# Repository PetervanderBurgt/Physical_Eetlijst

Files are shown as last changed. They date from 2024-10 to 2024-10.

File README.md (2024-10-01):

# Physical Eetlijst
Physical Eetlijst is a personal project to interface with the popular dutch student houses website [Eetlijst](https://eetlijst.nl/) and create a physical representation of the statuses of the website which shows who is there for dinner.

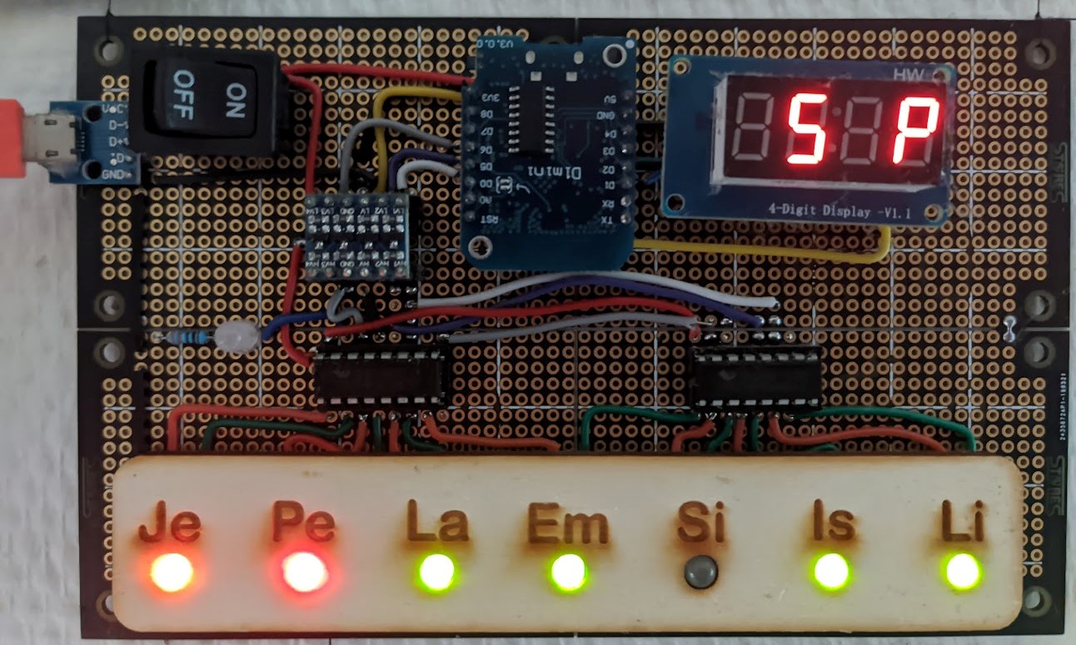
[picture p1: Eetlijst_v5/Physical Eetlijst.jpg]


## Inspiration
This Physical Eetlijst was first inspired by others living on the University of Twente campus, all credits for the idea should be given to them.
The model presented here is a simplified version just to show the statuses and how many people are eating, it is not possible to sign up for dinner through this physical device.

## Hardware
The hardware (and prototype board layout) can be seen in the Eetlijst v5 folder, it is given both as a [Fritzing](Eetlijst_v5/Eetlijst.fzz) and [png](Eetlijst_v5/Eetlijst_Hardware%20Breadboard%20layout.png) and [jpg](Eetlijst_v5/Eetlijst_Hardware%20Breadboard%20layout.jpg).
Pay close attention to the connections as it otherwise may not work.
For the Wemos D1 mini, the MCU is flipped in the image (meaning 5V should be in the upper right corner, and 3.3V should be in the Upper Left.
The necessary items are the following:

**Item**   | **Count** | **Description**
------------- | ------------- | -------------
**Necessities** ||
Prototype board | 1 | This should be approximately (32 by 50) for 7 people, this should be altered to fit.
Power connector breakout board | 1 | In the overview a USB micro is chosen, as that was what was available.
Power switch | 1 | Can be chosen as one sees fit.
Wemos D1 mini (clone) | 1 |Tthe brain of the operation is a ESP8266, in this case a clone Wemos D1 mini.
TM1637 | 1 | A simple display to show how many people will be eating.
Wires |N.A.| Some spare wires to connect everything.
Headers |N.A.| Some spare headers to make everything swappable.
**Indicators** ||
Blue LED | 1 | Indicator for when information is getting retrieved.
RG LED | x | A bicolour led, in my case Red and Green to show the status of the people. Get as many as there are people in Eetlijst, in this example 7.
Shift Register (74HC595) | x/4 | Shift register for driving LEDs, get the amount of bicolour LEDs divided by 4.
Level Shifter | 1 | To convert signals from 3.3V ESP8266 to 5V shift registers.
**OR** | | Instead of the above for indicators, there may be an easier option, this does require modifications for the hardware of the system.
Digital LED Strip (ws281x) | x + 1 | A digital LED strip may be easier than the above to indicate the people and when the system is retrieving information.

## Software
The Arduino IDE can be used to flash the software found in [Eetlijst_final_v5](Eetlijst_v5/Eetlijst_final_v5) to the Wemos D1 mini.
Before flashing, the different login credentials should be filled in [keys.h](Eetlijst_v5/Eetlijst_final_v5/keys.h).
In the place of the xxxxxxxx the Wi-Fi credentials, as well as the Eetlijst credentials should be filled in.

## Limitations
The current limitation of the system is that the ESP8266 does not work with enterprise networks, and will only work with simple home networks.
Furthermore, it is not possible to change your status from the device, this should still be done through the website or phone apps.

## Versions
There are two versions, the older one [Eetlijst_v4](Eetlijst_v4), is non-working, due to the updates given to Eetlijst itself.
The current version, [Eetlijst_v5](Eetlijst_v5), should be working and running.

## Support
This repository is for documentation purposes only, there will be no support for any issues. Questions are welcome, but it is not guaranteed to be fixed.

### License
[MIT](https://choosealicense.com/licenses/mit/)

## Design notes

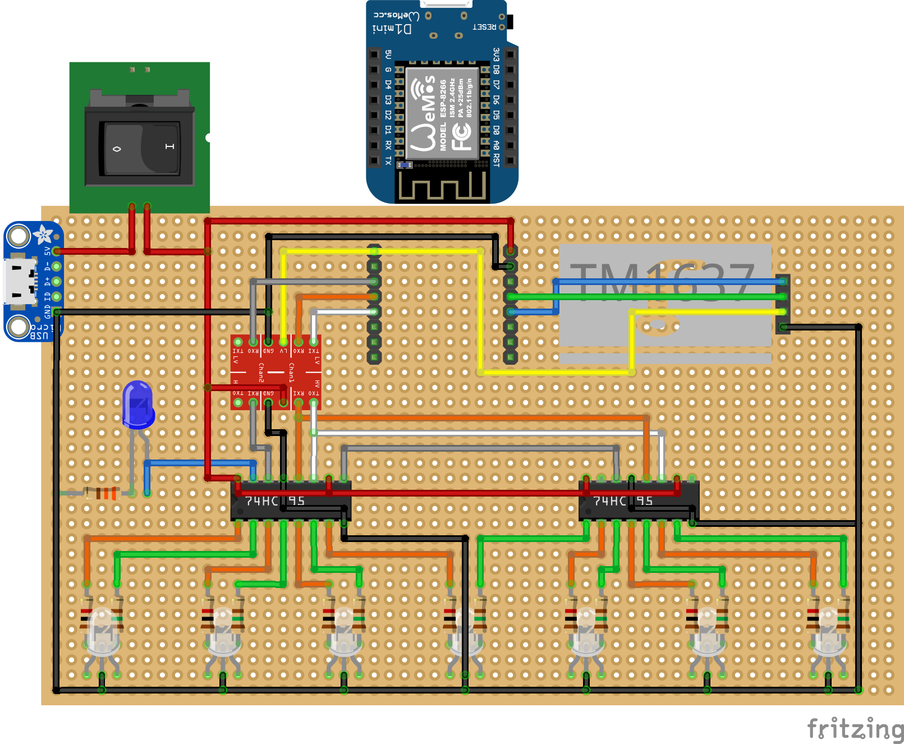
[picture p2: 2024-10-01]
Eetlijst_v5/Eetlijst_Hardware Breadboard layout.png

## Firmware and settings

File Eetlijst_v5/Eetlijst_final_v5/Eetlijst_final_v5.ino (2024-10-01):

//for general wifi and website connectivity
#include <ESP8266WiFi.h>
#include <ESP8266HTTPClient.h>
#include <WiFiClientSecure.h>
//for getting jsons
#include <ArduinoJson.h>
//for time
#include <WiFiUdp.h>
#include <NTPClient.h>


//Display
#include <TM1637Display.h>
#include "keys.h"

// WiFi parameters and eetlijst parameter to be configured to be configured
const char* ssid = DEFINED_SSID; // Hoofdlettergevoelig
const char* password = DEFINED_SSID_PASSWORD; // Hoofdlettergevoelig
const String Eetlijst_USERNAME = DEFINED_EETLIJST_USERNAME;
const String Eetlijst_PASSWORD = DEFINED_EETLIJST_PASSWORD;

//eetlijst parametes, in this example 7 people
const int noOfPeople = 7;
int red[noOfPeople];
int green[noOfPeople];
int blue = LOW;

//Display
// Module connection pins (Digital Pins)
#define CLK D2
#define DIO D3
TM1637Display display(CLK, DIO);

//ShiftRegister
#define latchPin D6
#define clockPin D5
#define dataPin D7

//variables for the token retrieval url and the api url
const char *token_url = "node.samenn.nl";
const char *api_url = "api.samenn.nl";
String retrieved_token = "";
//String which contains the number of people for query
const String Eetlijst_NUMBEROFPEOPLE = String(noOfPeople);

//should be in format yyyy-mm-dd (2023-03-21)
String current_date = "2023-03-20";
// string to be formatted to json
String returnedJsonString = "";

// arrays that will hold the order of the names, there eating statusses and their number of guests,
// and finally number of people that are eating
String actual_name_order[noOfPeople];
String actual_eating_status[noOfPeople];
int actual_number_of_guests[noOfPeople];
int hoeveelMeeEters = 0;

//variables for retriving the correct time
//offset in seconds from utc time
const long utcOffsetInSeconds = 3600;
WiFiUDP ntpUDP;
NTPClient timeClient(ntpUDP, "europe.pool.ntp.org", utcOffsetInSeconds);

//Wifi and httpclient variables
WiFiClientSecure wifiSecure;
HTTPClient http; //Declare an object of class HTTPClient

//ResetTimer variables
long previousMillis = 0;
const long interval = 1000 * 60 * 5;           // interval after which to reset (milliseconds)

void setup() {
  Serial.begin(9600);
  //set the values for coloring of lights
  blue = true;
  for (int i = 0; i < noOfPeople; i++) {
    red[i] = LOW;
    green[i] = LOW;
  }

  //display
  display.setBrightness(0x0f);
  //set Error on display
  if (retrieved_token == "") {
    setDisplay();
  }
  //Shift Register
  pinMode(latchPin, OUTPUT);
  pinMode(clockPin, OUTPUT);
  pinMode(dataPin, OUTPUT);
  setShiftRegisters();

  //connect to the wifi
  Serial.print("Bezig met verbinden");
  WiFi.hostname("Eetlijst ESP");
  WiFi.begin(ssid, password); // Connect to WiFi
  // while wifi not connected yet, print '.'
  // then after it connected, get out of the loop
  while (WiFi.status() != WL_CONNECTED) {
    delay(500);
    Serial.print(".");
  }
  // Verbonden.
  Serial.println("OK!");
  // Access Point (SSID).
  Serial.print("SSID: ");
  Serial.println(WiFi.SSID());
  // IP adres.
  Serial.print("IP: ");
  Serial.println(WiFi.localIP());
  // Signaalsterkte.
  long rssi = WiFi.RSSI();
  Serial.print("Signaal sterkte (RSSI): ");
  Serial.print(rssi);
  Serial.println(" dBm");
  Serial.println("");
}

void loop() {
  //if this is the first time turning on, retrieve all information, otherwise wait for timeout
  if (retrieved_token == "") {
    // get the current date
    current_date = getDate();
    //check whether it has updated and it is not still unix 0 (1970)
    while (current_date[0] != '2') {
      current_date = getDate();
    }
    // get the bearer authorization token for api usage
    getToken();
    // use api to retrieve the information displayed by eetlijst
    returnedJsonString = getEters();
    // parese the information into the arrays used for display
    parseJsonString(returnedJsonString);

    //count how many people eat
    for (int i = 0; i < noOfPeople; i++) {
      if ((actual_eating_status[i] == "cook") || (actual_eating_status[i] == "eat_only") || (actual_eating_status[i] == "got_groceries")) {
                hoeveelMeeEters++;
      } else {
        //do not count to how many people are eating
      }
      hoeveelMeeEters = hoeveelMeeEters + actual_number_of_guests[i];
    }

    for (int i = 0; i < noOfPeople; i++) {
      //set lights red and green array
      red[i] = setRedLight(actual_eating_status[i]);
      green[i] = setGreenLight(actual_eating_status[i]);
    }
    //set blue light off
    blue = LOW;

    //print all information to the serial monitor
    for (int i = 0; i < 7; i++) Serial.print(actual_name_order[i] + ", ");
    Serial.println();
    for (int i = 0; i < 7; i++) Serial.print(actual_eating_status[i] + ", ");
    Serial.println();
    for (int i = 0; i < 7; i++) Serial.print(String(actual_number_of_guests[i]) + ", ");
    Serial.println();
    Serial.println("================================================");

    Serial.print("Number of people that are eating: ");
    Serial.println(hoeveelMeeEters);

    //set lights red and green array and (eten array)
    for (int i = 0; i < 7; i++) Serial.print(String(red[i]) + ", ");
    Serial.println();
    for (int i = 0; i < 7; i++) Serial.print(String(green[i]) + ", ");
    Serial.println();

    //set display
    setDisplay();

    //set shift register
    setShiftRegisters();


  } else {
    //Restart after interval to make sure that data displayed is up to date
    unsigned long currentMillis = millis();
    if (currentMillis - previousMillis > interval) {
      previousMillis = currentMillis;
      Serial.println("Resetting ESP");
      ESP.restart();
    }
  }
}

void setDisplay() {
  uint8_t data[] = { 0xff, 0xff, 0xff, 0xff };
  display.clear();
  // Zet mee eters
  if (retrieved_token == "") {
    data[0] = SEG_A | SEG_D | SEG_E | SEG_F | SEG_G; // letter E
    data[1] = SEG_E | SEG_G;                 // letter r
  } else if (hoeveelMeeEters > 20) {
    data[0] = display.encodeDigit(2);
    data[1] = display.encodeDigit(hoeveelMeeEters % 20);
  } else if (hoeveelMeeEters > 10) {
    data[0] = display.encodeDigit(1);
    data[1] = display.encodeDigit(hoeveelMeeEters % 10);
  } else {
    data[0] = 0x00;
    data[1] = display.encodeDigit(hoeveelMeeEters);
  }
  data[2] = 0x00;
  data[3] = SEG_A | SEG_B | SEG_E | SEG_F | SEG_G; //letter P
  display.setSegments(data);
}

void setShiftRegisters() {
  int shiftOutValue1 = 0;
  int shiftOutValue2 = 0;
  if (blue)     shiftOutValue1 = shiftOutValue1 + pow(2, 0); //0x00000001 /1

  if (red[0])   shiftOutValue1 = shiftOutValue1 + pow(2, 1); //0x00000010 /1
  if (green[0]) shiftOutValue1 = shiftOutValue1 + pow(2, 2); //0x00000100 /1
  if (red[1])   shiftOutValue1 = shiftOutValue1 + pow(2, 3); //0x00001000 /1
  if (green[1]) shiftOutValue1 = shiftOutValue1 + pow(2, 4); //0x00010000 /1
  if (red[2])   shiftOutValue1 = shiftOutValue1 + pow(2, 5); //0x00100000 /1
  if (green[2]) shiftOutValue1 = shiftOutValue1 + pow(2, 6); //0x01000000 /1
  if (red[3])   shiftOutValue1 = shiftOutValue1 + pow(2, 7); //0x10000000 /1
  if (green[3]) shiftOutValue2 = shiftOutValue2 + pow(2, 1); //0x00000010 /2
  if (red[4])   shiftOutValue2 = shiftOutValue2 + pow(2, 2); //0x00000100 /2
  if (green[4]) shiftOutValue2 = shiftOutValue2 + pow(2, 3); //0x00001000 /2
  if (red[5])   shiftOutValue2 = shiftOutValue2 + pow(2, 4); //0x00010000 /2
  if (green[5]) shiftOutValue2 = shiftOutValue2 + pow(2, 5); //0x00100000 /2
  if (red[6])   shiftOutValue2 = shiftOutValue2 + pow(2, 6); //0x01000000 /2
  if (green[6]) shiftOutValue2 = shiftOutValue2 + pow(2, 7); //0x10000000 /2

  Serial.println(shiftOutValue1, BIN);
  Serial.println(shiftOutValue2, BIN);
  // take the latchPin low so
  // the LEDs don't change while you're sending in bits:
  digitalWrite(latchPin, LOW);
  // shift out the bits:
  shiftOut(dataPin, clockPin, MSBFIRST, shiftOutValue2);
  shiftOut(dataPin, clockPin, MSBFIRST, shiftOutValue1);
  //take the latch pin high so the LEDs will light up:
  digitalWrite(latchPin, HIGH);
  // pause before next value:
}

int setRedLight(String eet) {
  //should be low if off and high if on
  if (eet == "cook" || eet == "not_attending") {
    return HIGH;
  } else {
    return LOW;
  }
}

int setGreenLight(String eet) {
  //should be low if off and high if on
  if (eet == "cook" || eet == "eat_only") {
    return HIGH;
  } else {
    return LOW;
  }
}

int getToken() {
  WiFiClientSecure client;
  client.setInsecure(); // this is the magical line that makes everything work

  Serial.print("HTTPS Connecting");
  int r = 0; //retry counter
  while ((!client.connect(token_url, 443)) && (r < 30)) {
    delay(100);
    Serial.print(".");
    r++;
  }
  if (r == 30) {
    Serial.println("Connection failed");
  }
  else {
    Serial.println("Connected to web");
  }
  const char *token_url_extra = "/api/v1/auth/eetlijst/";
  String login_token = "{\"login\":\"" + Eetlijst_USERNAME + "\", \"pass\":\"" + Eetlijst_PASSWORD + "\"}";
  const char *body = login_token.c_str();

  StaticJsonBuffer<200> jsonBuffer;
  JsonObject& root = jsonBuffer.createObject();
  root["login"] = "login";
  root["pass"] = "passwd";
  root.printTo(Serial);
  Serial.println();


  char postStr[40];

  sprintf(postStr, "POST %s HTTP/1.1", token_url_extra);  // put together the string for HTTP POST

  client.println(postStr);
  client.print("Host: "); client.println(token_url);
  client.println("Content-Type: application/json");
  client.print("Content-Length: "); client.println(root.measureLength());
  client.println();    // extra `\r\n` to separate the http header and http body
  root.printTo(client);
  Serial.println("request sent");


  unsigned long timeout = millis();
  while (client.available() == 0) {
    if (millis() - timeout > 5000)
    { Serial.println(">>> Client Timeout !");
      client.stop(); return -1;
    }
  } // Read all the lines of the reply from server and print them to Serial
  String line = "";
  while (client.available())
  { line = client.readStringUntil('\r');
  }
  Serial.println();
  //  Serial.println("line = " + line);
  retrieved_token = line.substring(11, line.length() - 2); //Add Json parsing properly
  //  Serial.println(retrieved_token);
  Serial.println("Token Retrieved");

  Serial.println("closing connection");
}

String getEters() {
  WiFiClientSecure client;
  client.setInsecure(); // this is the magical line that makes everything work

  Serial.print("HTTPS Connecting");
  int r = 0; //retry counter
  while ((!client.connect(api_url, 443)) && (r < 30)) {
    delay(100);
    Serial.print(".");
    r++;
  }
  if (r == 30) {
    Serial.println("Connection failed");
  }
  else {
    Serial.println("Connected to web");
  }
  const char *token_url_extra = "/v1/graphql";
  //  const String query = "\nquery\x20MyQuery {\n    eetschema_event(\n      where: {start_date: {_gte: \"2023-03-21T00:00:00+00:00\", _lt: \"2023-03-21T23:00: 00 + 00: 00\"}}\n    ) {\n      group_id\n      event_attendees {\n        attending_user {\n          name\n        }\n        status\n        number_guests\n      }\n    }\n    eetschema_users_in_group(where: {order: {_lte: \"6\"}}) {\n      order\n      user {\n        name\n      }\n    }\n  }";

  const char *jsonquery = "{\"query\":\" query MyQuery ($time_in: timestamptz!,$time_out: timestamptz!,$no_of_people: Int!) {    eetschema_event(      where: {start_date: {_gte: $time_in, _lt:$time_out}}    ) {      event_attendees {        attending_user {          name        }        status        number_guests      }    }    eetschema_users_in_group(where: {order: {_lt: $no_of_people}}) {      order      user {        name      }    }  }\",";

  String variables_retrieving = "\"variables\":{\"time_in\":\"" + current_date + "T00:00:00+00:00\",\"time_out\":\"" + current_date + "T23:00:00+00:00\",\"no_of_people\":\"" + Eetlijst_NUMBEROFPEOPLE + "\"}}";
  const char *jsonvariables = variables_retrieving.c_str();
  //  const char* jsonvariables = "\"variables\":{\"time_in\":\"2023-03-21T00:00:00+00:00\",\"time_out\":\"2023-03-21T23:00:00+00:00\",\"no_of_people\":\"7\"}}";

  int newSize = strlen(jsonquery)  + strlen(jsonvariables) + 1;
  // Allocate new buffer
  char *body = (char *)malloc(newSize);

  // do the copy and concat
  strcpy(body, jsonquery);
  strcat(body, jsonvariables); // or strncat

  //  const char *body = "{\"query\":\"\\n          query EventSingleEventQuery($event_id: uuid!) {\\n            eetschema_event_by_pk(id: $event_id) {\\n              start_date\\n              name\\n              id\\n              description\\n              end_date\\n              open\\n              updated_at\\n              created_at\\n              closed_by\\n              linked_expenses_aggregate(where: { deleted: { _eq: false } }) {\\n                aggregate {\\n                  sum {\\n                    payed_amount\\n                  }\\n                }\\n              }\\n            }\\n            eetschema_event_attendees(where: { event_id: { _eq: $event_id } }) {\\n              status\\n              user_id\\n              number_guests\\n              comment\\n            }\\n          }\\n        \",\"variables\":{\"event_id\":\"a91be5d8-2143-4829-8c00-79b6fda00f3d\"},\"operationName\":\"EventSingleEventQuery\"}";
  //  const char *body = "{\"query\":\" query MyQuery ($time_in: timestamptz!,$time_out: timestamptz!,$no_of_people: Int!) {    eetschema_event(      where: {start_date: {_gte: $time_in, _lt:$time_out}}    ) {      event_attendees {        attending_user {          name        }        status        number_guests      }    }    eetschema_users_in_group(where: {order: {_lte: $no_of_people}}) {      order      user {        name      }    }  }\",\"variables\":{\"time_in\":\"2023-03-21T00:00:00+00:00\",\"time_out\":\"2023-03-21T23:00:00+00:00\",\"no_of_people\":\"6\"}}";

  char postStr[40];

  sprintf(postStr, "POST %s HTTP/1.1", token_url_extra);  // put together the string for HTTP POST

  client.println(postStr);
  client.print("Host: "); client.println(api_url);
  client.println("Content-Type: application/json");
  client.print("authorization: Bearer "); client.println(retrieved_token);
  client.print("Content-Length: "); client.println(strlen(body));
  client.println();    // extra `\r\n` to separate the http header and http body
  client.println(body);
  Serial.println("request sent");


  unsigned long timeout = millis();
  while (client.available() == 0) {
    if (millis() - timeout > 10000)
    { Serial.println(">>> Client Timeout !");
      client.stop();
    }
  } // Read all the lines of the reply from server and print them to Serial
  const int lines_max = 20;  // array capacity
  String lines[lines_max];
  int line_counter = 0;
  while (client.available())
  {
    lines[line_counter] = client.readStringUntil('\r');
    line_counter++;
  }
  int jsonLineStartingWithBracket = -1;
  for (int i = 0; i < line_counter; i++) {
    if (lines[i].substring(0,15).indexOf("data") > 0) {
      jsonLineStartingWithBracket = i;
    }
  }
  String jsonReturned = lines[jsonLineStartingWithBracket];
  //  Serial.println(jsonReturned);
  Serial.println("Json Retrieved");

  Serial.println("closing connection");
  return jsonReturned;
}

String getDate() {
  timeClient.begin();

  timeClient.update();

  time_t epochTime = timeClient.getEpochTime();
  struct tm *ptm = gmtime ((time_t *)&epochTime);
  char formattedDatechar[(4 + 1 + 2 + 1 + 2)];
  sprintf(formattedDatechar, "%04d-%02d-%02d", ptm->tm_year + 1900, ptm->tm_mon + 1, ptm->tm_mday);

  String formattedDate = String(formattedDatechar);
  Serial.println(formattedDate);
  return formattedDate;
}

void parseJsonString(String returnedJson) {
  const size_t capacity = JSON_ARRAY_SIZE(1) + 2 * JSON_ARRAY_SIZE(7) + 16 * JSON_OBJECT_SIZE(1) + 8 * JSON_OBJECT_SIZE(2) + 7 * JSON_OBJECT_SIZE(3) + 750;
  DynamicJsonBuffer jsonBuffer(capacity);

  JsonObject& root = jsonBuffer.parseObject(returnedJson);

  String eating_status_names[noOfPeople];
  String eating_status[noOfPeople];
  int number_of_guests[noOfPeople];

  String name_order[noOfPeople];
  int int_order[noOfPeople];

  JsonArray& event_attendees = root["data"]["eetschema_event"][0]["event_attendees"];
  JsonArray& eetschema_order = root["data"]["eetschema_users_in_group"];

  for (int i = 0; i < noOfPeople; i++) {
    eating_status_names[i] = (event_attendees[i]["attending_user"]["name"]).as<String>();
    eating_status[i] = (event_attendees[i]["status"]).as<String>();
    number_of_guests[i] = event_attendees[i]["number_guests"];

    name_order[i] = eetschema_order[i]["user"]["name"].as<String>();
    int_order[i] = eetschema_order[i]["order"];
  }



  //initalize to doesnt know and zero eaters
  for (int i = 0; i < noOfPeople; i++) {
    actual_eating_status[i] = "dont_know_yet";
    actual_number_of_guests[i] = 0;
  }

  for (int i = 0; i < noOfPeople; i++) {
    actual_name_order[int_order[i]] = name_order[i];
  }

  for (int i = 0; i < noOfPeople; i++) {
    for (int j = 0; j < noOfPeople; j++) {
      if (actual_name_order[i] == eating_status_names[j]) {
        actual_eating_status[i] = eating_status[j];
        actual_number_of_guests[i] = number_of_guests[j];
      }
    }
  }
}
